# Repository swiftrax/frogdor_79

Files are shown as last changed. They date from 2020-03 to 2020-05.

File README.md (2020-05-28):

### I provide this keyboard without liability and without any guarantees regarding functionality, as expressed in the Creative Commons license under which all of these PCBs are licensed.

KiCad and Fusion360 files are included 

Tested Working on USB 2.0

QMK Can be found in my fork

# Supported Layouts
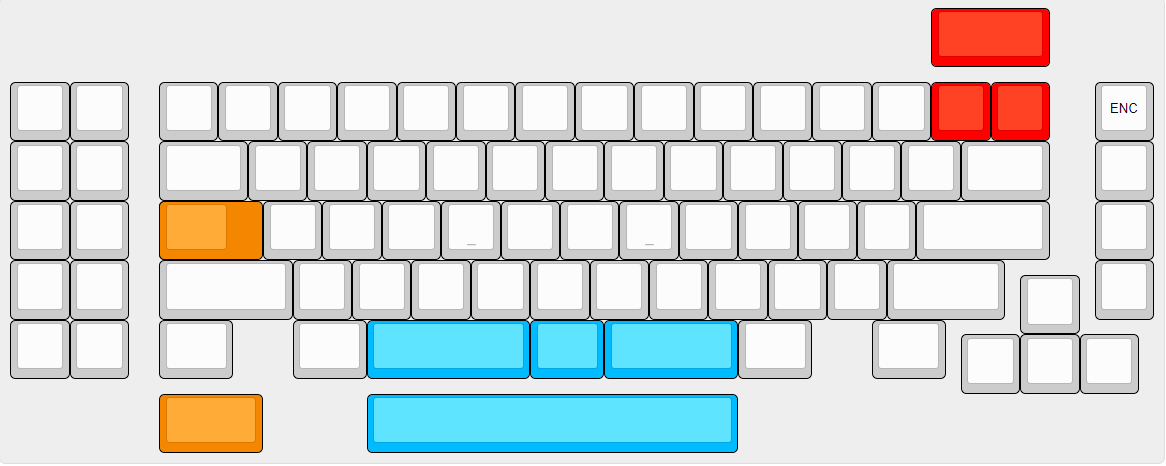
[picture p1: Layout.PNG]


# Images
[Imgur Album](https://imgur.com/a/08Liv0p)
PCB Top
PCB Bottom

# Case
[M3 Spacers](https://www.mcmaster.com/94868a162) x 4 

[M3 Screws](https://www.mcmaster.com/93070a057) 1 pack 

Reccomended Manufacturers for cases: **Ponoko for Acrylic, SendCutSend for Metal** 

Plate x 1 3mm Acrylic 

Midlayer x 2 3mm Acrylic 

Backplate x 1 3mm Acrylic 

*Note if using an aluminum plate use O-rings as a spacer

# QMK
[Keyboard](https://github.com/swiftrax/qmk_firmware/tree/master/keyboards/frogdor)

`make frogdor:default`

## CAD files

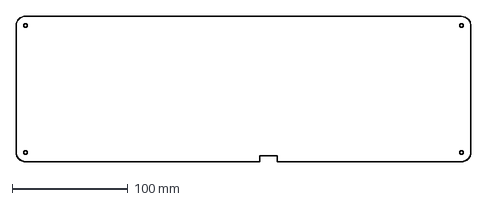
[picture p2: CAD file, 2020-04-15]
Case/Case_DXF/backplate.dxf
392.1 x 125.4 mm

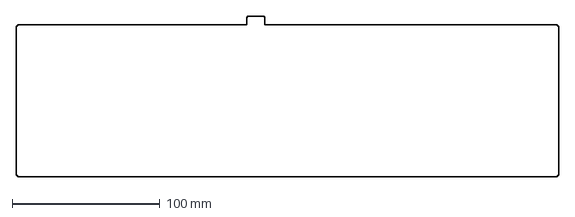
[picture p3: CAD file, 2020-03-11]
KiCad/EdgeCuts.dxf
367.0 x 108.7 mm

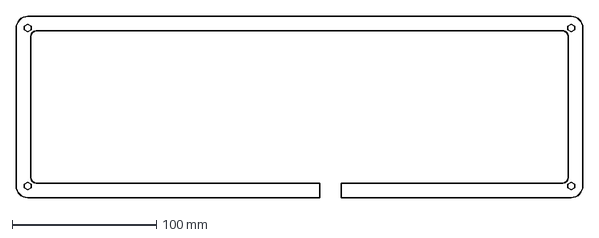
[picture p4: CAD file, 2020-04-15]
Case/Case_DXF/midlayer.dxf
392.1 x 125.4 mm

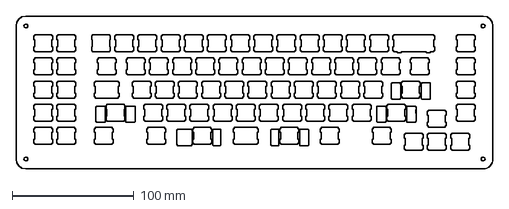
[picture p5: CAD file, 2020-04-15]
Case/Case_DXF/plate.dxf
392.1 x 125.4 mm

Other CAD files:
Case/FrogdorCase.f3d

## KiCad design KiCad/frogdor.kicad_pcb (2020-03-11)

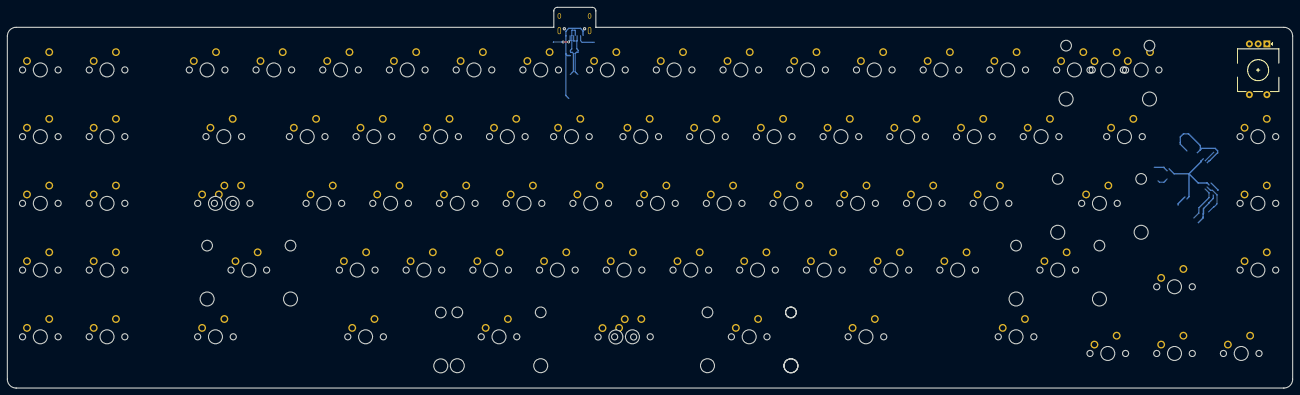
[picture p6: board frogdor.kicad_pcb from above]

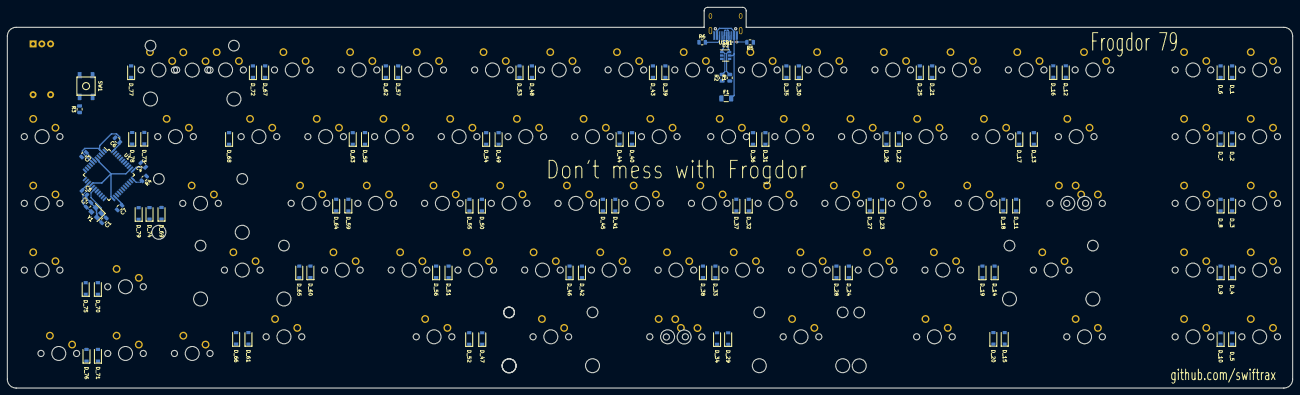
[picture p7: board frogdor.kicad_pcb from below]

Board: 2 copper layers, 367.0 x 108.7 mm, 180 parts (98 on the bottom side), 117 nets.

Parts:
C1, C2: 22pF; C_0805_2012Metric
C3: 1uF; C_0805_2012Metric
C4, C5, C6: 0.1uF; C_0805_2012Metric
C7: 10uF; C_0805_2012Metric
D_1, D_2, D_3, D_4, D_5, D_6, D_7, D_8, D_9, D_10, D_11, D_12, D_13, D_14, D_15, D_16, D_17, D_18, D_19, D_20, D_21, D_22, D_23, D_24, D_25, D_26, D_27, D_28, D_29, D_30, D_31, D_32, D_33, D_34, D_35, D_36, D_37, D_38, D_39, D_40, D_41, D_42, D_43, D_44, D_45, D_46, D_47, D_48, D_49, D_50, D_51, D_52, D_53, D_54, D_55, D_56, D_57, D_58, D_59, D_60, D_61, D_62, D_63, D_64, D_65, D_66, D_67, D_68, D_69, D_70, D_71, D_72, D_73, D_74, D_75, D_76, D_77, D_78, D_79: D; D_SOD-123
F1: 500mA; Fuse_1206_3216Metric
K_1, K_2, K_3, K_4, K_5, K_6, K_7, K_8, K_9, K_10, K_12, K_17, K_18, K_19, K_20, K_22, K_23, K_24, K_25, K_26, K_27, K_28, K_29, K_31, K_32, K_33, K_34, K_36, K_37, K_38, K_39, K_41, K_42, K_43, K_44, K_45, K_46, K_47, K_48, K_50, K_51, K_52, K_53, K_55, K_56, K_57, K_58, K_59, K_60, K_61, K_62, K_64, K_65, K_66, K_68, K_69, K_70, K_72, K_73, K_74, K_76, K_77, K_78, K_80, K_81: KEYSW; MXOnly-1U-NoLED
K_11, K_15, K_21, K_35, K_54, K_63: KEYSW; MXOnly-1.25U-NoLED
K_13, K_75: KEYSW; MXOnly-1.5U-NoLED
K_14, K_49, K_71: KEYSW; MXOnly-2.25U-NoLED
K_16: KEYSW; MXOnly-1.75U-NoLED
K_30: KEYSW; MXOnly-2.75U-NoLED
K_40: KEYSW; MXOnly-6.25U-NoLED
K_67, K_79: KEYSW; MXOnly-2U-NoLED
R1, R2: 22; R_0805_2012Metric
R3, R4: 10k; R_0805_2012Metric
R5, R6: 5.1k; R_0805_2012Metric
SW1: SW_Push; SKQG-1155865
SW2: Rotary_Encoder_Switch; RotaryEncoder_EC11
U1: ATmega32U4-AU; TQFP-44_10x10mm_P0.8mm
U2: SRV05-4; SOT-23-6
USB1: HRO-TYPE-C-31-M-12; HRO-TYPE-C-31-M-12-HandSoldering
Y1: 16MHz; Crystal_SMD_3225-4Pin_3.2x2.5mm

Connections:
+5V: C4.1, C5.1, C6.1, C7.1, F1.1, R3.1, U1.2, U1.7, U1.14, U1.24, U1.34, U1.44
D+: R2.2, U2.1, USB1.6, USB1.8
D-: R1.2, U2.6, USB1.5, USB1.7
ENCA: SW2.A, U1.11
ENCB: SW2.B, U1.10
ENCS1: D_79.2, SW2.S1
ENCS2: K_80.1, K_81.1, SW2.S2, U1.8
GND: C1.2, C2.2, C3.2, C4.2, C5.2, C6.2, C7.2, R4.1, R5.1, R6.1, SW1.1, SW2.C, U1.5, U1.15, U1.23, U1.35, U1.43, U2.2, USB1.1, USB1.12, USB1.13, Y1.2, Y1.4
unnamed: C1.1, U1.17, Y1.1
unnamed: C2.1, U1.16, Y1.3
unnamed: C3.1, U1.6
unnamed: D_1.2, K_1.2
unnamed: D_2.2, K_2.2
unnamed: D_3.2, K_3.2
unnamed: D_4.2, K_4.2
unnamed: D_5.2, K_5.2
unnamed: D_6.2, K_6.2
unnamed: D_7.2, K_7.2
unnamed: D_8.2, K_8.2
unnamed: D_9.2, K_9.2
unnamed: D_10.2, K_10.2
unnamed: D_11.2, K_11.2, K_16.2
unnamed: D_12.2, K_12.2
unnamed: D_13.2, K_13.2
unnamed: D_14.2, K_14.2
unnamed: D_15.2, K_15.2
unnamed: D_16.2, K_17.2
unnamed: D_17.2, K_18.2
unnamed: D_18.2, K_19.2
unnamed: D_19.2, K_20.2
unnamed: D_20.2, K_21.2
unnamed: D_21.2, K_22.2
unnamed: D_22.2, K_23.2
unnamed: D_23.2, K_24.2
unnamed: D_24.2, K_25.2
unnamed: D_25.2, K_26.2
unnamed: D_26.2, K_27.2
unnamed: D_27.2, K_28.2
unnamed: D_28.2, K_29.2
unnamed: D_29.2, K_30.2
unnamed: D_30.2, K_31.2
unnamed: D_31.2, K_32.2
unnamed: D_32.2, K_33.2
unnamed: D_33.2, K_34.2
unnamed: D_34.2, K_35.2, K_40.2
unnamed: D_35.2, K_36.2
unnamed: D_36.2, K_37.2
unnamed: D_37.2, K_38.2
unnamed: D_38.2, K_39.2
unnamed: D_39.2, K_41.2
unnamed: D_40.2, K_42.2
unnamed: D_41.2, K_43.2
unnamed: D_42.2, K_44.2
unnamed: D_43.2, K_45.2
unnamed: D_44.2, K_46.2
unnamed: D_45.2, K_47.2
unnamed: D_46.2, K_48.2
unnamed: D_47.2, K_49.2
unnamed: D_48.2, K_50.2
unnamed: D_49.2, K_51.2
unnamed: D_50.2, K_52.2
unnamed: D_51.2, K_53.2
unnamed: D_52.2, K_54.2
unnamed: D_53.2, K_55.2
unnamed: D_54.2, K_56.2
unnamed: D_55.2, K_57.2
unnamed: D_56.2, K_58.2
unnamed: D_57.2, K_59.2
unnamed: D_58.2, K_60.2
unnamed: D_59.2, K_61.2
unnamed: D_60.2, K_62.2
unnamed: D_61.2, K_63.2
unnamed: D_62.2, K_64.2
unnamed: D_63.2, K_65.2
unnamed: D_64.2, K_66.2
unnamed: D_65.2, K_67.2
unnamed: D_66.2, K_68.2
unnamed: D_67.2, K_69.2
unnamed: D_68.2, K_70.2
unnamed: D_69.2, K_71.2
unnamed: D_70.2, K_72.2
unnamed: D_71.2, K_73.2
unnamed: D_72.2, K_74.2, K_79.2
unnamed: D_73.2, K_75.2
unnamed: D_74.2, K_76.2
unnamed: D_75.2, K_77.2
unnamed: D_76.2, K_78.2
unnamed: D_77.2, K_80.2
unnamed: D_78.2, K_81.2
unnamed: R1.1, U1.3
unnamed: R2.1, U1.4
unnamed: R3.2, SW1.2, U1.13
unnamed: R4.2, U1.33
unnamed: R5.2, USB1.4
unnamed: R6.2, USB1.10
VBUS: F1.2, U2.5, USB1.2, USB1.11
col0: K_1.1, K_2.1, K_3.1, K_4.1, K_5.1, U1.41
col1: K_6.1, K_7.1, K_8.1, K_9.1, K_10.1, U1.40
col2: K_11.1, K_12.1, K_13.1, K_14.1, K_15.1, K_16.1, U1.39
col3: K_17.1, K_18.1, K_19.1, K_20.1, K_21.1, U1.38
col4: K_22.1, K_23.1, K_24.1, K_25.1, U1.37
col5: K_26.1, K_27.1, K_28.1, K_29.1, K_30.1, U1.36
col6: K_31.1, K_32.1, K_33.1, K_34.1, U1.32
col7: K_35.1, K_36.1, K_37.1, K_38.1, K_39.1, K_40.1, U1.31
col8: K_41.1, K_42.1, K_43.1, K_44.1, U1.30
col9: K_45.1, K_46.1, K_47.1, K_48.1, K_49.1, U1.29
col10: K_50.1, K_51.1, K_52.1, K_53.1, K_54.1, U1.28
col11: K_55.1, K_56.1, K_57.1, K_58.1, U1.27
col12: K_59.1, K_60.1, K_61.1, K_62.1, K_63.1, U1.26
col13: K_64.1, K_65.1, K_66.1, K_67.1, K_68.1, U1.25
col14: K_69.1, K_70.1, K_71.1, K_72.1, K_73.1, U1.22
col15: K_74.1, K_75.1, K_76.1, K_77.1, K_78.1, K_79.1, U1.21
row0: D_1.1, D_6.1, D_12.1, D_16.1, D_21.1, D_25.1, D_30.1, D_35.1, D_39.1, D_43.1, D_48.1, D_53.1, D_57.1, D_62.1, D_67.1, D_72.1, D_77.1, U1.12
row1: D_2.1, D_7.1, D_13.1, D_17.1, D_22.1, D_26.1, D_31.1, D_36.1, D_40.1, D_44.1, D_49.1, D_54.1, D_58.1, D_63.1, D_68.1, D_73.1, D_78.1, U1.18
row2: D_3.1, D_8.1, D_11.1, D_18.1, D_23.1, D_27.1, D_32.1, D_37.1, D_41.1, D_45.1, D_50.1, D_55.1, D_59.1, D_64.1, D_69.1, D_74.1, D_79.1, U1.20
row3: D_4.1, D_9.1, D_14.1, D_19.1, D_24.1, D_28.1, D_33.1, D_38.1, D_42.1, D_46.1, D_51.1, D_56.1, D_60.1, D_65.1, D_70.1, D_75.1, U1.19
row4: D_5.1, D_10.1, D_15.1, D_20.1, D_29.1, D_34.1, D_47.1, D_52.1, D_61.1, D_66.1, D_71.1, D_76.1, U1.1

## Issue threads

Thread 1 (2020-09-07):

Do you have BOM for the PCB components?

geocine, 2020-09-07:
Thank you for open-sourcing this project, do you have  BOM for the components that I need soldered unto the PCB?

Closed 2021-03-08.

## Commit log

2020-03-11 Remove Tracks
    [EdgeCuts.dxf, Endgame_Rev2_bom_jlc.csv, frogdor.kicad_pcb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]
2020-03-16 Add Files needed
    [FrogdorCase.f3d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]
2020-04-13 Update Case
    [FrogdorCase.f3d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]
2020-04-14 Remove Plates.kicad
    [frogdor_plates-B_Cu.gbr, frogdor_plates-B_Mask.gbr, frogdor_plates-B_SilkS.gbr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]
2020-04-15 Add DXF and EPS files for the case
    [backplate.dxf, midlayer.dxf, plate.dxf]
2020-05-28 Add PCB renders
